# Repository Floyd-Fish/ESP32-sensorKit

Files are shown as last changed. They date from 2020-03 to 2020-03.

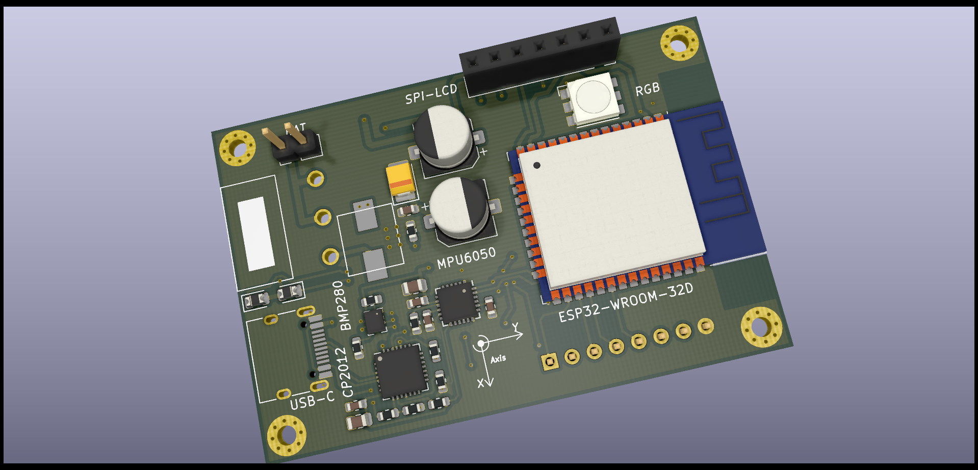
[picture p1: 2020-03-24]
Hardware/img/ESP32-sensorKit_A.png

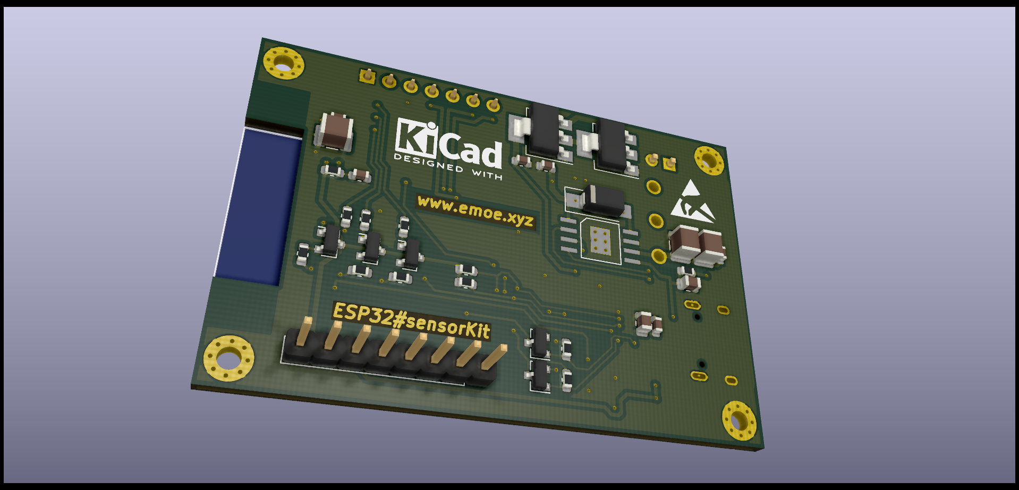
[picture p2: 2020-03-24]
Hardware/img/ESP32-sensorKit_B.png

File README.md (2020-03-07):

# ESP32-sensorKit

<center>


</center>

I made this project for test only...  
Also I'm preparing for the next generation "End-World-Kit",which means End-World-Kit V2.0.  

## Progress
- Start Project --- 2020.3.5  
- Complete schematic design --- 2020.2.6  
- Complete PCB layout --- 2020.3.7  
- To be continued...

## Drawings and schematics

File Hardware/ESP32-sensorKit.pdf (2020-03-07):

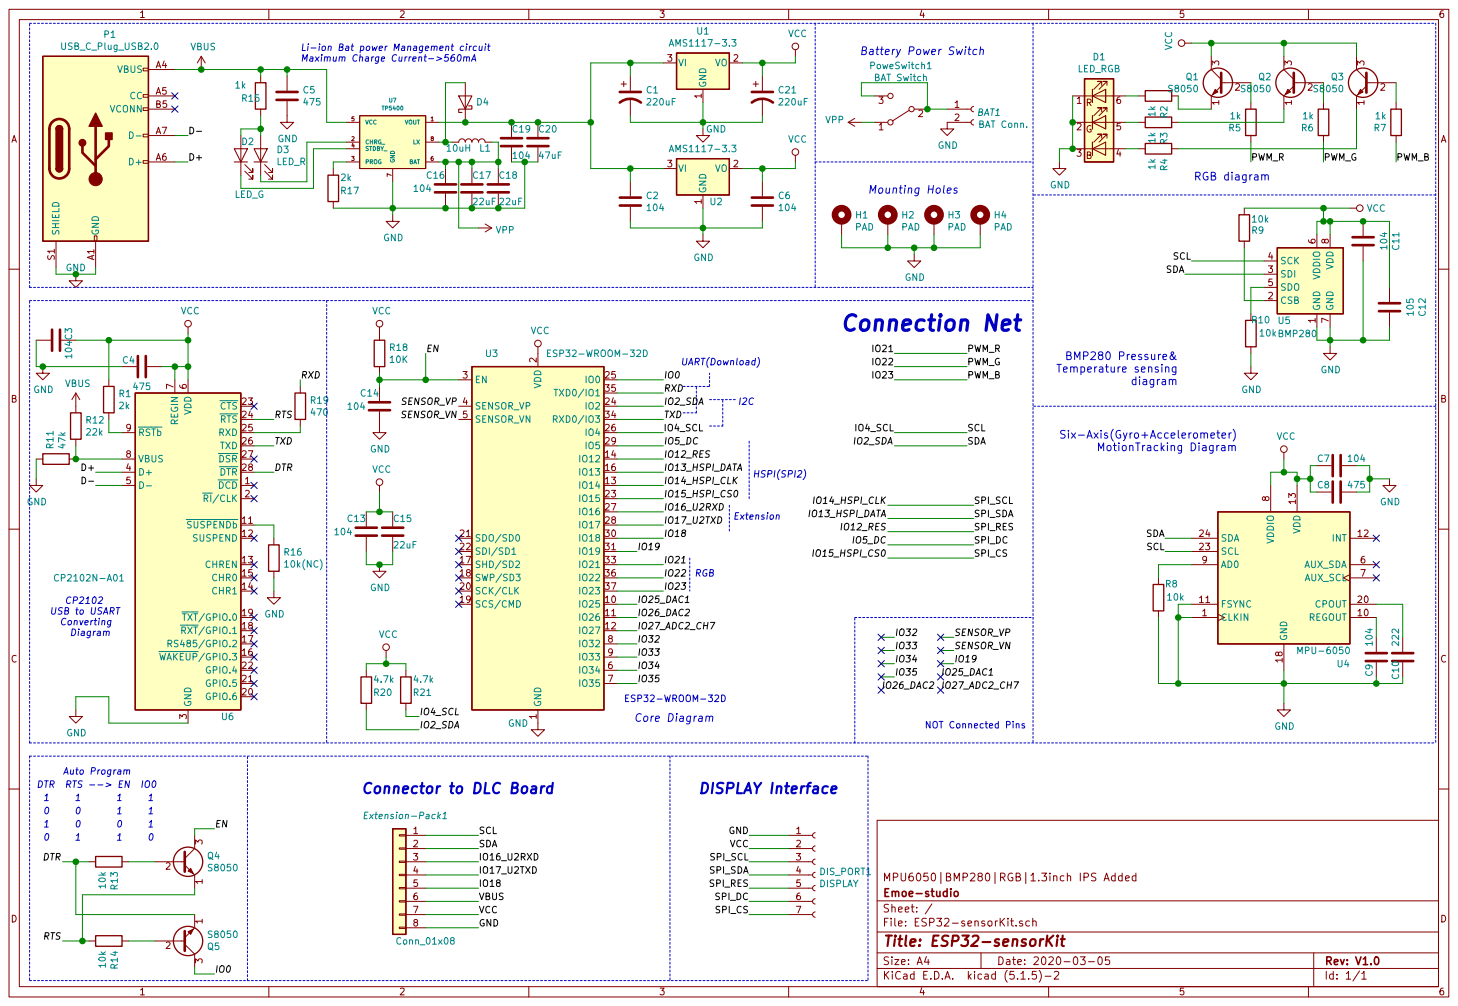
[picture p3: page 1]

8 U5BMP280 GND A1 VBUS A4 CC A5 D+ A6 D- A7 VCONN B5 SHIELD S1 P1 USB_C_Plug_USB2.0 R1

1 VO 2 VI 3 U1 AMS1117-3.3 CLKIN 1 REGOUT 10 FSYNC 11
VCC GNDGND GND

Li-ion Bat power Management circuit
Maximum Charge Current->560mA

1 CSB 2 SDI 3 SCK 4 SDO 5 VDDIO

2 SCK/CLK 20 SDO/SD0 21 SDI/SD1 22

Six-Axis(Gyro+Accelerometer)
MotionTracking Diagram

Id: 1/1 Title: ESP32-sensorKit File: ESP32-sensorKit.sch Sheet: / Emoe-studio MPU6050|BMP280|RGB|1.3inch IPS Added

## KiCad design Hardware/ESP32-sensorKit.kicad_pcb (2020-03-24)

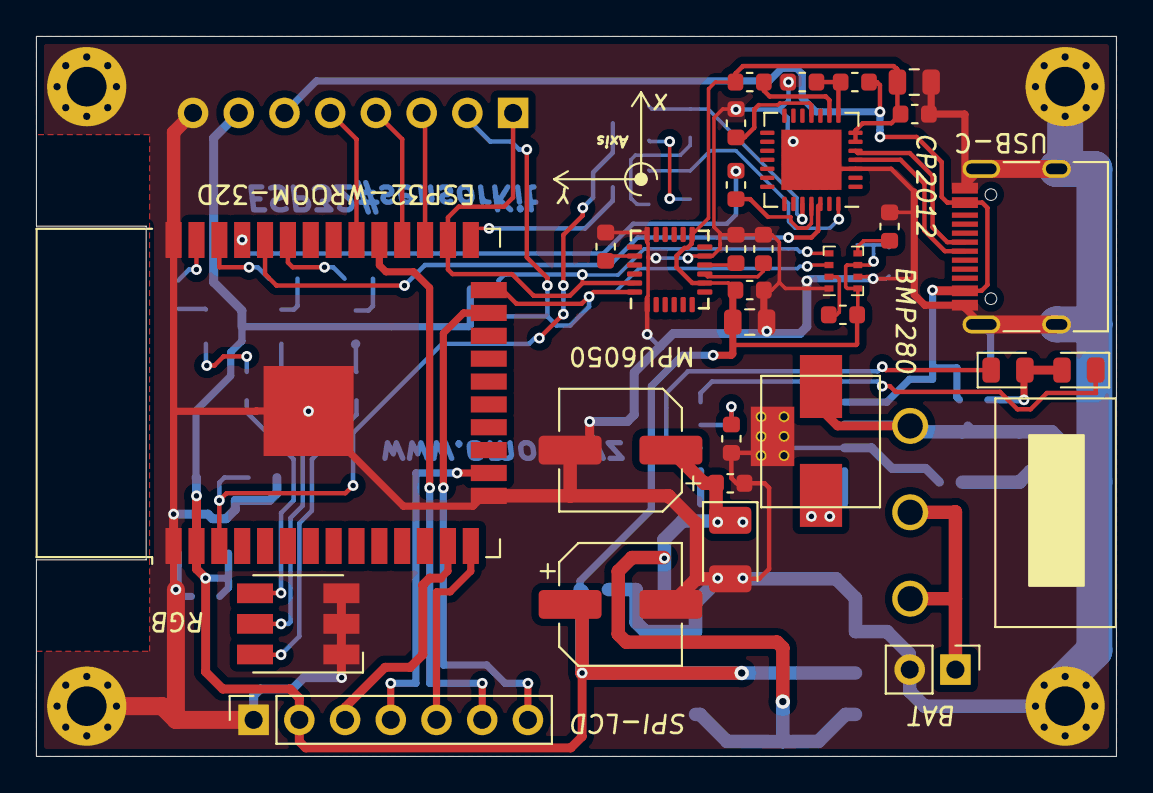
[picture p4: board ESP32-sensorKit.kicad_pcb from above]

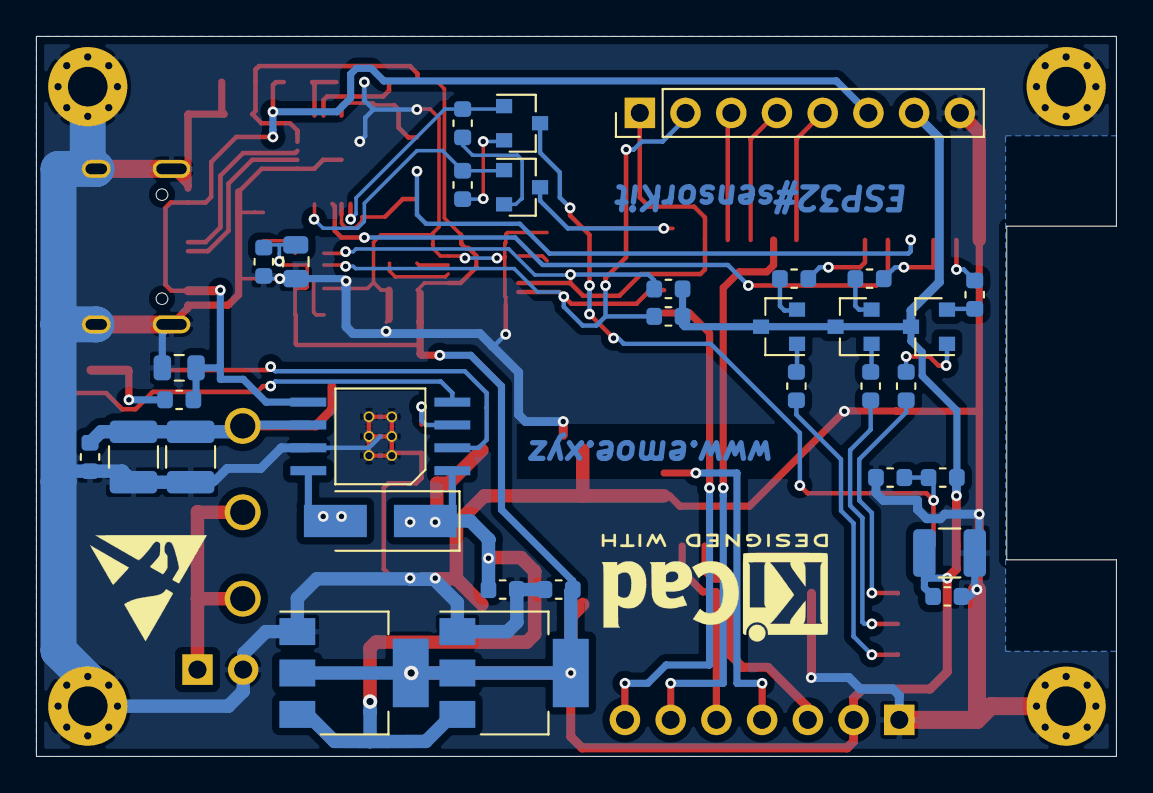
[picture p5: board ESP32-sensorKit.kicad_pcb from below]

Board: 2 copper layers, 60.0 x 40.0 mm, 68 parts (33 on the bottom side), 52 nets.

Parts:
BAT1: BAT Conn.; PinHeader_1x02_P2.54mm_Vertical
C1, C21: 220uF; CP_Elec_6.3x5.4
C2, C3, C6, C7, C9, C11, C13, C14, C16, C19: 104; C_0603_1608Metric
C4, C5, C8: 475; C_0805_2012Metric
C10: 222; C_0603_1608Metric
C12: 105; C_0805_2012Metric
C15, C17, C18: 22uF; C_1210_3225Metric
C20: 47uF; CP_EIA-3528-15_AVX-H_Pad1.50x2.35mm_HandSolder
D1: LED_RGB; LED_RGB_5050-6
D2: LED_G; D_0805_2012Metric
D3: LED_R; D_0805_2012Metric
D4: D_Schottky; D_SMA_Handsoldering
DIS_PORT1: DISPLAY; PinSocket_1x07_P2.54mm_Vertical
Extension-Pack1: Conn_01x08; PinHeader_1x08_P2.54mm_Vertical
H1, H2, H3, H4: PAD; MountingHole_2.2mm_M2_Pad_Via
L1: 10uH; 06030
P1: USB_C_Plug_USB2.0; USB_C_Receptacle_HRO_TYPE-C-31-M-12
PoweSwitch1: BAT Switch; SS12D06
Q1, Q2, Q3, Q4, Q5: S8050; SOT-23
R1, R17: 2k; R_0603_1608Metric
R2, R3, R4, R5, R6, R7, R15: 1k; R_0603_1608Metric
R8, R9, R10, R13, R14: 10k; R_0603_1608Metric
R11: 47k; R_0603_1608Metric
R12: 22k; R_0603_1608Metric
R16: 10k(NC); R_0603_1608Metric
R18: 10K; R_0603_1608Metric
R19: 470; R_0603_1608Metric
R20, R21: 4.7k; R_0603_1608Metric
U1, U2: AMS1117-3.3; SOT-223-3_TabPin2
U3: ESP32-WROOM-32D; ESP32-WROOM-32
U4: MPU-6050; InvenSense_QFN-24_4x4mm_P0.5mm
U5: BMP280; Bosch_LGA-8_2x2.5mm_P0.65mm_ClockwisePinNumbering
U6: CP2102N-A01; QFN-28-1EP_5x5mm_P0.5mm_EP3.35x3.35mm
U7: TP5400; ESOP-8

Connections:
/D+: P1.A6, U6.4
/D-: P1.A7, U6.5
/DTR: Q5.1, R13.2, U6.28
/EN: C14.1, Q4.3, R18.2, U3.3
/IO0: Q5.3, U3.25
/IO2_SDA: Extension-Pack1.2, R20.1, U3.24, U4.24, U5.3
/IO4_SCL: Extension-Pack1.1, R21.1, U3.26, U4.23, U5.4
/IO5_DC: DIS_PORT1.6, U3.29
/IO12_RES: DIS_PORT1.5, U3.14
/IO13_HSPI_DATA: DIS_PORT1.4, U3.16
/IO14_HSPI_CLK: DIS_PORT1.3, U3.13
/IO15_HSPI_CS0: DIS_PORT1.7, U3.23
/IO16_U2RXD: Extension-Pack1.3, U3.27
/IO17_U2TXD: Extension-Pack1.4, U3.28
/IO18: Extension-Pack1.5, U3.30
/IO21: R5.1, U3.33
/IO22: R6.1, U3.36
/IO23: R7.1, U3.37
/RTS: Q4.1, R14.2, U6.24
/RXD: R19.1, U3.35
/TXD: U3.34, U6.26
GND: BAT1.2, C1.2, C2.2, C3.2, C4.2, C5.2, C6.2, C7.2, C8.2, C9.1, C10.1, C11.1, C12.1, C13.2, C14.2, C15.2, C16.2, C17.2, C18.2, C19.2, C20.2, C21.2, D1.1, D1.2, D1.3, DIS_PORT1.1, Extension-Pack1.8, H1.1, H2.1, H3.1, H4.1, P1.A1, P1.A12, P1.B1, P1.B12, P1.S1, R8.1, R10.1, R11.1, R16.2, R17.1, U1.1, U2.1, U3.1, U3.15, U3.38, U3.39, U4.1, U4.11, U4.18, U5.1, U5.7, U6.3, U6.29, U7.7, U7.9, U7.10
unnamed: BAT1.1, PoweSwitch1.2, PoweSwitch1.3
unnamed: C1.1, C2.1, C19.1, C20.1, D4.1, U1.3, U2.3, U7.1
unnamed: C9.2, U4.10
unnamed: C10.2, U4.20
unnamed: D1.4, R4.2
unnamed: D1.5, R3.2
unnamed: D1.6, R2.2
unnamed: D2.1, U7.4
unnamed: D2.2, D3.2, R15.1
unnamed: D3.1, U7.2
unnamed: D4.2, L1.1, U7.8
unnamed: Q1.1, R2.1
unnamed: Q1.2, R5.2
unnamed: Q2.1, R3.1
unnamed: Q2.2, R6.2
unnamed: Q3.1, R4.1
unnamed: Q3.2, R7.2
unnamed: Q4.2, R13.1
unnamed: Q5.2, R14.1
unnamed: R1.2, U6.9
unnamed: R8.2, U4.9
unnamed: R9.1, U5.2
unnamed: R10.2, U5.5
unnamed: R11.2, R12.2, U6.8
unnamed: R16.1, U6.11
unnamed: R17.2, U7.3
unnamed: R19.2, U6.25
VBUS: C5.1, Extension-Pack1.6, P1.A4, P1.A9, P1.B4, P1.B9, R12.1, R15.2, U7.5
VCC: C3.1, C4.1, C6.1, C7.1, C8.1, C11.2, C12.2, C13.1, C15.1, C21.1, DIS_PORT1.2, Extension-Pack1.7, Q1.3, Q2.3, Q3.3, R1.1, R9.2, R18.1, R20.2, R21.2, U1.2, U2.2, U3.2, U4.8, U4.13, U5.6, U5.8, U6.6, U6.7
VPP: C16.1, C17.1, C18.1, L1.2, PoweSwitch1.1, U7.6

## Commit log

2020-03-10 Fix PCB bugs
    [ESP32-sensorKit-B_Cu.gbr, ESP32-sensorKit-B_Mask.gbr, ESP32-sensorKit-B_Paste.gbr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]
2020-03-24 Update PCB gerber
    [ESP32-sensorKit-B_Cu.gbr, ESP32-sensorKit-B_Mask.gbr, ESP32-sensorKit-B_Paste.gbr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]
